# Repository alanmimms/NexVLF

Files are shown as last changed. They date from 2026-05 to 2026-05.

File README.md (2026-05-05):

# NexVLF
This is software defined radio hardware and software for VLF 40kHz to
300kHz range with high noise immunity, dynamic range, sensitivity, and
a built in 1m diameter loop antenna. It could be used to fool around
with VLF, to add a WWVB decoder to your shack (one is planned in
software), or whatever you like.

# Architecture

NexVLF uses an STM32H753 microcontroller to control and shovel bits
from the AK5572 24-bit audio codec into a USB2 (480Mb/s "high speed")
audio interface. A host CPU runs an app built for Linux, MacOS, and
Windows supplying the DSP functions to demodulate and tune the SDR
samples and a flexible and easily extensible receiver GUI mostly
written in Lua.

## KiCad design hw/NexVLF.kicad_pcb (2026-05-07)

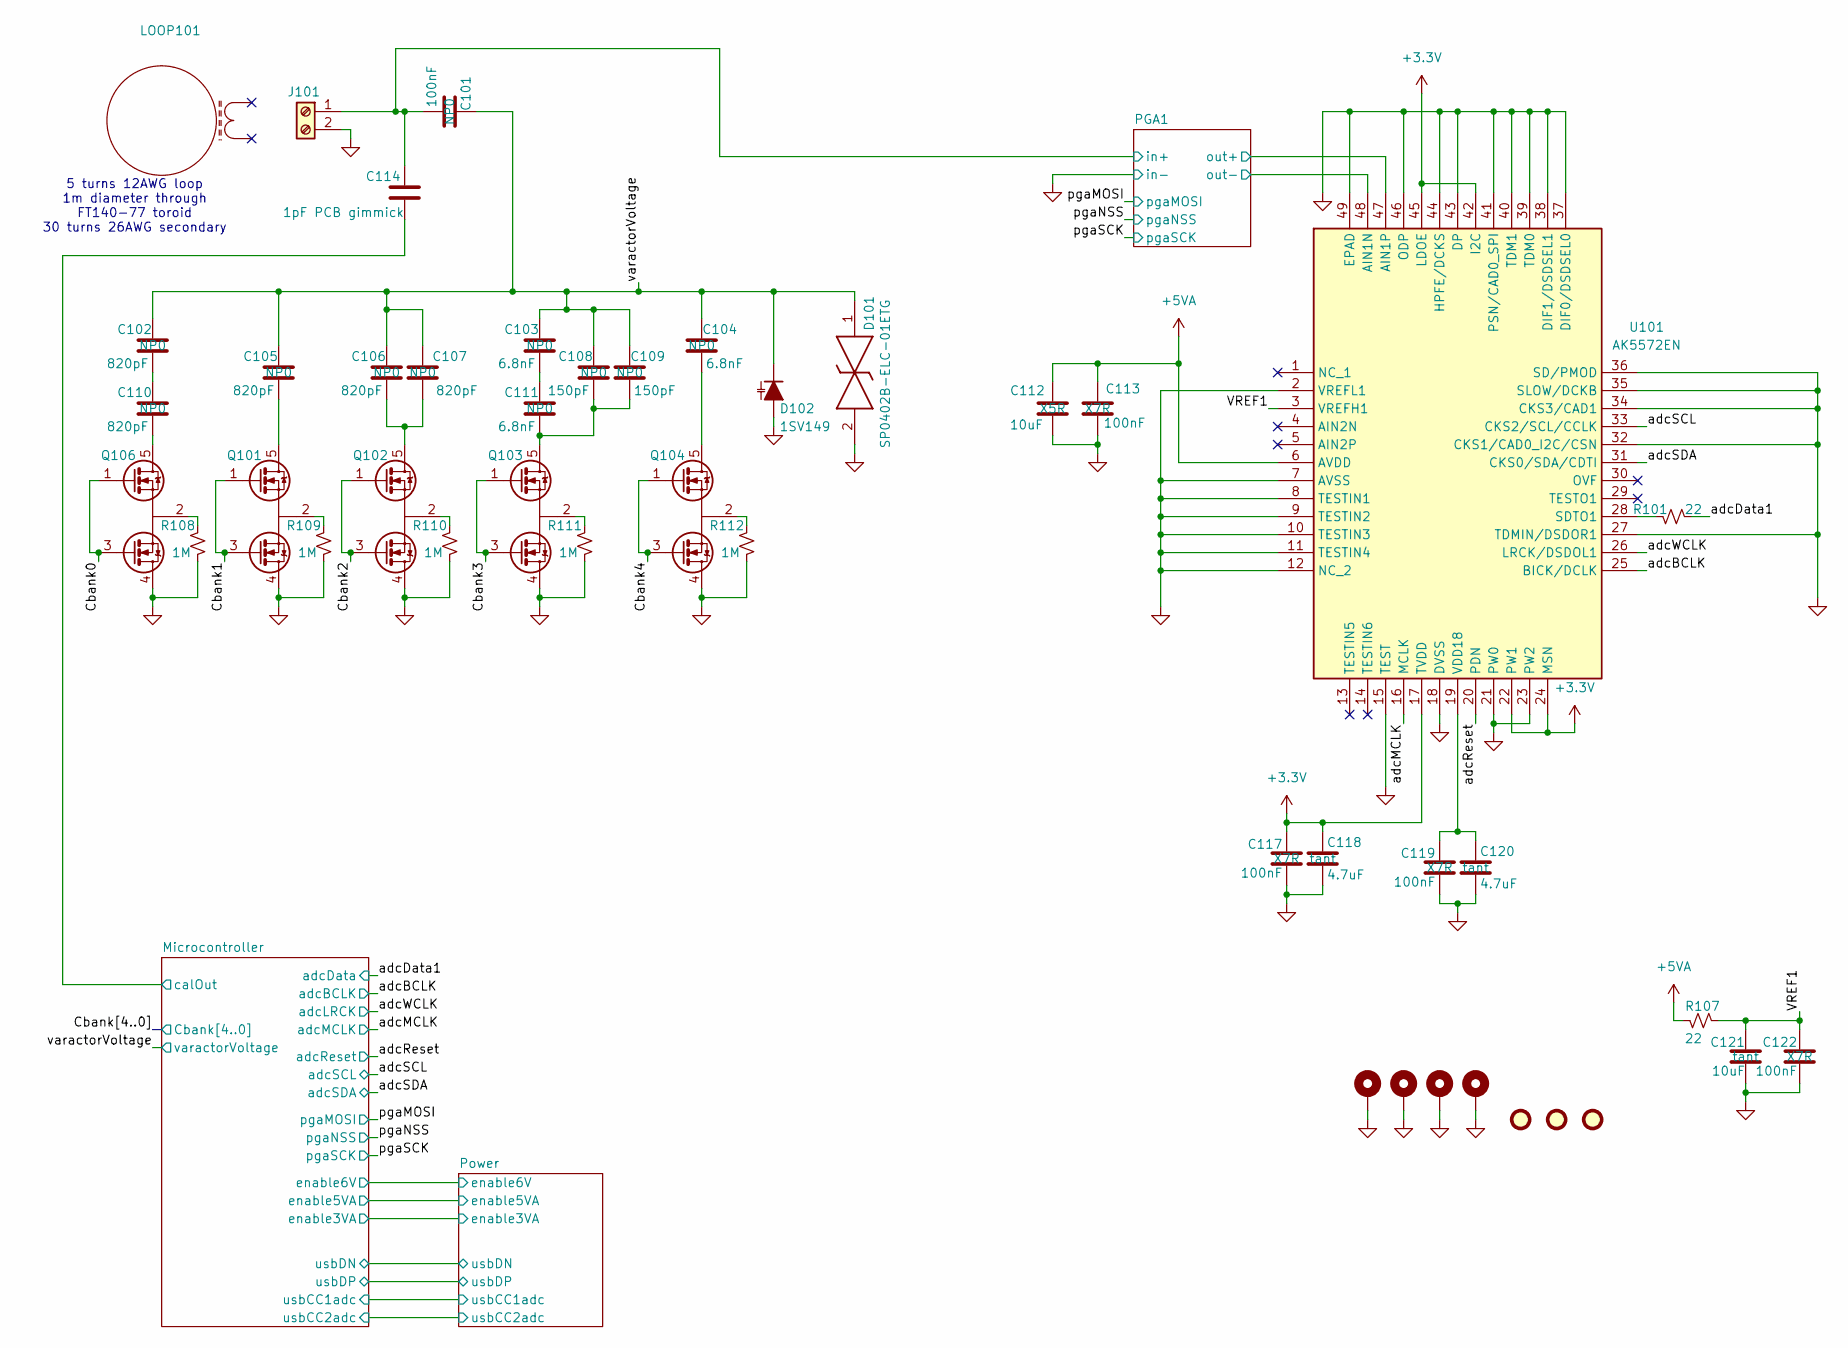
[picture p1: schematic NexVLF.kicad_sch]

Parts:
C101: 100nF; C_1206_3216Metric; MPN GRM3195C2A104JA01D; LCSC_PN C170182
C102, C105, C106, C107, C110: 820pF; C_1206_3216Metric; MPN GRM3195C2A104JA01D; LCSC_PN C170182
C103, C104, C111: 6.8nF; C_1206_3216Metric; MPN GRM3195C2A104JA01D; LCSC_PN C170182
C108, C109: 150pF; C_1206_3216Metric; MPN GRM3195C2A104JA01D; LCSC_PN C170182
C112: 10uF; C_0402_1005Metric; MPN GRM155R61E105KE11D; LCSC_PN C301928
C113, C117, C119, C122: 100nF; C_0402_1005Metric; MPN C0805F104K1RACAUTO; LCSC_PN C24452
C114: 1pF PCB gimmick; PCB-gimmick-1pF
C118, C120: 4.7uF; C_0805_2012Metric; MPN 298D475X9010M2T; LCSC_PN C18535241
C121: 10uF; C_0805_2012Metric; MPN TAJD106K050RNJ; LCSC_PN C4983748
D101: SP0402B-ELC-01ETG; D_0402_1005Metric; MPN SP0402B-ELC-01ETG; LCSC_PN C1974049
D102: 1SV149; TO-92-2
FID101, FID102, FID103: Fiducial; Fiducial_0.5mm_Mask1.5mm
H101, H102, H103, H104: MountingHole_Pad; MountingHole_3.2mm_M3_DIN965_Pad
J101: ANT; Altech_AK300_1x02_P5.00mm_45-Degree
LOOP101: (no value)
Q101, Q102, Q103, Q104, Q106: DMN32D2LDF; SOT-353_SC-70-5
R101, R107: 22; R_0402_1005Metric; JLCPCBpn C4258780
R108, R109, R110, R111, R112: 1M; R_0402_1005Metric; JLCPCBpn C4258780
U101: AK5572EN; QFN50P700X700X100-49N-D; Mouser Part Number 412-AK5572EN

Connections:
+3.3V: C117.2, C118.2, U101.17 (TVDD), U101.22 (PW1), U101.24 (MSN), U101.42 (I2C), U101.45 (LDOE); also elsewhere on the board
+5VA: C112.1, C113.1, R107.2, U101.6 (AVDD); also elsewhere on the board
/Cbank0: Q106.1 (G1), Q106.3 (G2); also elsewhere on the board
/Cbank1: Q101.1 (G1), Q101.3 (G2); also elsewhere on the board
/Cbank2: Q102.1 (G1), Q102.3 (G2); also elsewhere on the board
/Cbank3: Q103.1 (G1), Q103.3 (G2); also elsewhere on the board
/Cbank4: Q104.1 (G1), Q104.3 (G2); also elsewhere on the board
/PGA1/in+: C101.2, C114.1, J101.1; also elsewhere on the board
/PGA1/out+: U101.47 (AIN1P); also elsewhere on the board
/PGA1/out-: U101.48 (AIN1N); also elsewhere on the board
/VREF1: C121.1, C122.1, R107.1, U101.3 (VREFH1)
/adcBCLK: U101.25 (BICK/DCLK); also elsewhere on the board
/adcData1: R101.1; also elsewhere on the board
/adcMCLK: U101.16 (MCLK); also elsewhere on the board
/adcReset: U101.20 (PDN); also elsewhere on the board
/adcSCL: U101.33 (CKS2/SCL/CCLK); also elsewhere on the board
/adcSDA: U101.31 (CKS0/SDA/CDTI); also elsewhere on the board
/adcWCLK: U101.26 (LRCK/DSDOL1); also elsewhere on the board
/varactorVoltage: C101.1, C102.1, C103.1, C104.1, C105.1, C106.1, C107.1, C108.1, C109.1, D101.1, D102.1 (K); also elsewhere on the board
GND: C112.2, C113.2, C117.1, C118.1, C119.1, C120.1, C121.2, C122.2, D101.2, D102.2 (A), H101.1, H102.1, H103.1, H104.1, J101.2, Q101.4 (D2), Q102.4 (D2), Q103.4 (D2), Q104.4 (D2), Q106.4 (D2), R108.2, R109.2, R110.2, R111.2, R112.2, U101.2 (VREFL1), U101.7 (AVSS), U101.8 (TESTIN1), U101.9 (TESTIN2), U101.10 (TESTIN3), U101.11 (TESTIN4), U101.12 (NC_2), U101.15 (TEST), U101.18 (DVSS), U101.21 (PW0), U101.23 (PW2), U101.27 (TDMIN/DSDOR1), U101.32 (CKS1/CAD0_I2C/CSN), U101.34 (CKS3/CAD1), U101.35 (SLOW/DCKB), U101.36 (SD/PMOD), U101.37 (DIF0/DSDSEL0), U101.38 (DIF1/DSDSEL1), U101.39 (TDM0), U101.40 (TDM1), U101.41 (PSN/CAD0_SPI), U101.43 (DP), U101.44 (HPFE/DCKS), U101.46 (ODP), U101.49 (EPAD); also elsewhere on the board
unnamed: C102.2, C110.1
unnamed: C103.2, C111.1
unnamed: C105.2, Q101.5 (D1)
unnamed: Q101.2 (S), R109.1
unnamed: C106.2, C107.2, Q102.5 (D1)
unnamed: Q102.2 (S), R110.1
unnamed: C108.2, C109.2, C111.2, Q103.5 (D1)
unnamed: Q103.2 (S), R111.1
unnamed: C104.2, Q104.5 (D1)
unnamed: Q104.2 (S), R112.1
unnamed: C110.2, Q106.5 (D1)
unnamed: Q106.2 (S), R108.1
unnamed: R101.2, U101.28 (SDTO1)
unnamed: C119.2, C120.2, U101.19 (VDD18)

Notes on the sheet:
5 turns 12AWG loop 1m diameter through FT140-77 toroid 30 turns 26AWG secondary

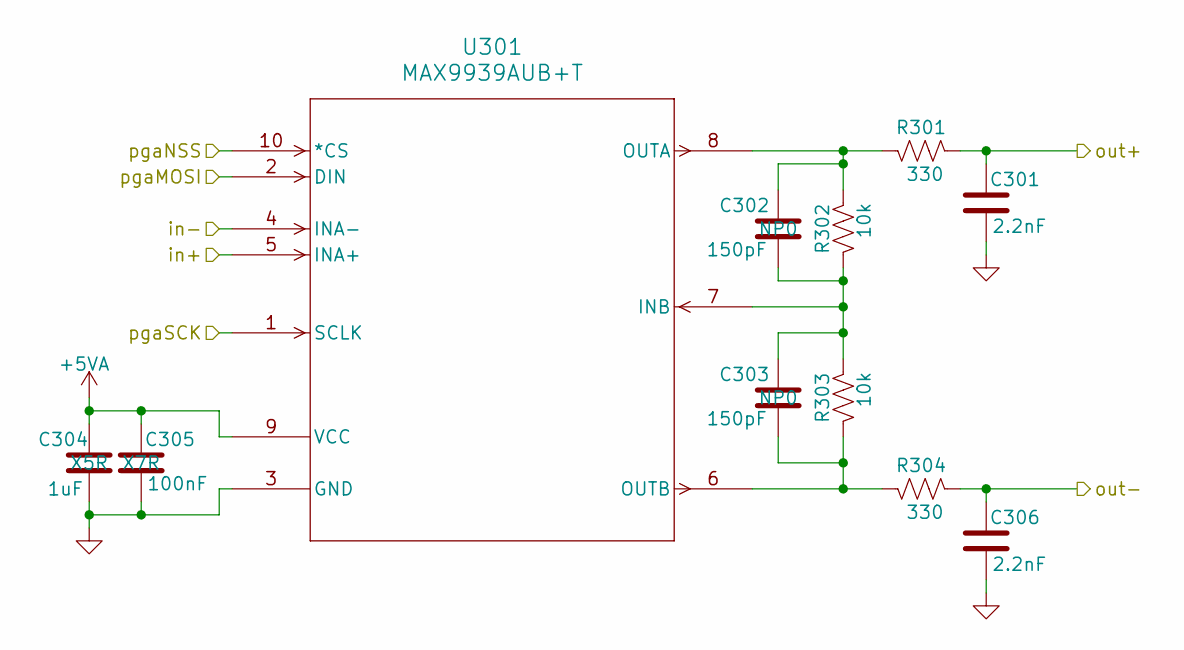
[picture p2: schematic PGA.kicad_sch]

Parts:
C301, C306: 2.2nF; C_0603_1608Metric
C302, C303: 150pF; C_0603_1608Metric; MPN 06033A151FAT2A; LCSC_PN C107038
C304: 1uF; C_0402_1005Metric; MPN GRM155R61E105KE11D; LCSC_PN C301928
C305: 100nF; C_0402_1005Metric; MPN C0805F104K1RACAUTO; LCSC_PN C24452
R301, R304: 330; R_0402_1005Metric; LCSC_PN C854274
R302, R303: 10k; R_0402_1005Metric; JLCPCBpn C723366
U301: MAX9939AUB+T; SOP50P490X110-10N; LCSC_PN C2057611

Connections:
+5VA: C304.1, C305.1, U301.9 (VCC); also elsewhere on the board
/PGA1/in+: U301.5 (INA+); also elsewhere on the board
/PGA1/out+: C301.1, R301.2; also elsewhere on the board
/PGA1/out-: C306.1, R304.2; also elsewhere on the board
/pgaMOSI: U301.2 (DIN); also elsewhere on the board
/pgaNSS: U301.10 (*CS); also elsewhere on the board
/pgaSCK: U301.1 (SCLK); also elsewhere on the board
GND: C301.2, C304.2, C305.2, C306.2, U301.3 (GND), U301.4 (INA-); also elsewhere on the board
unnamed: C302.2, C303.1, R302.2, R303.1, U301.7 (INB)
unnamed: C302.1, R301.1, R302.1, U301.8 (OUTA)
unnamed: C303.2, R303.2, R304.1, U301.6 (OUTB)

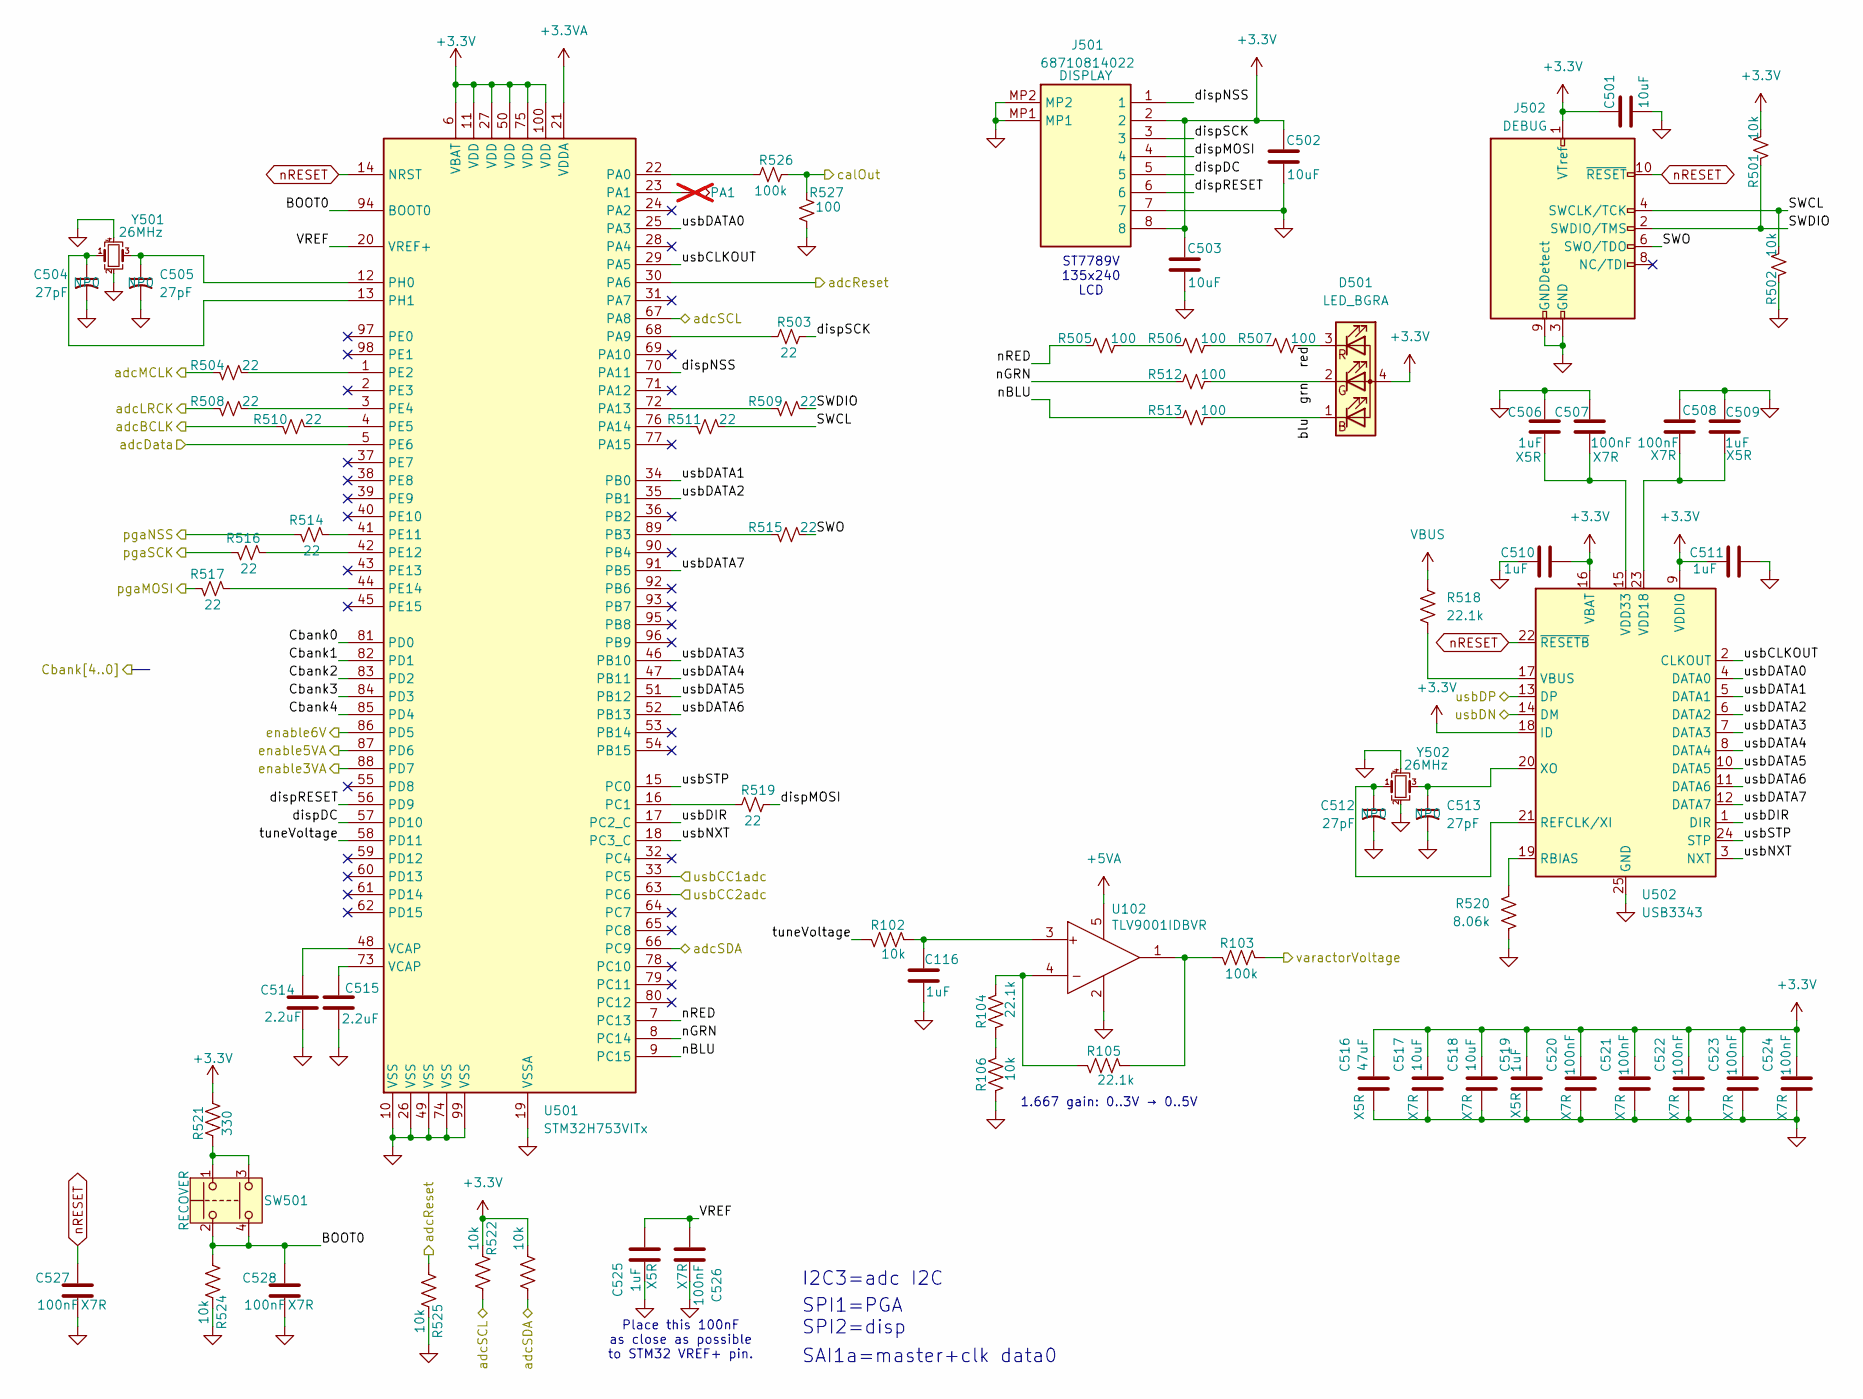
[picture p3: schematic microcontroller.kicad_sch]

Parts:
C116, C506, C509, C510, C511: 1uF; C_0402_1005Metric; Manufacturer_Part_Number GRM155R61E105KE11D; Mouser Part Number 81-GRM155R61E105KE1D
C501, C503: 10uF; C_0603_1608Metric; MPN 81-GXT155R71E223KE1D; LCSC_PN C327087
C502, C517, C518: 10uF; C_0603_1608Metric; Manufacturer_Part_Number 81-GXT155R71E223KE1D; Mouser Part Number 963-MLAST168BB5106MT
C504: 27pF; C_0402_1005Metric; LCSC_PN C107045
C505, C512, C513: 27pF; C_0402_1005Metric; JLCPCBpn C107045
C507, C508, C524: 100nF; C_0402_1005Metric; MPN C0805F104K1RACAUTO; LCSC_PN C24452
C514, C515: 2.2uF; C_0603_1608Metric; LCSC_PN C100082
C516: 47uF; C_1206_3216Metric; MPN TCTAL1A107M8R-V1; LCSC_PN C403725
C519, C525: 1uF; C_0402_1005Metric; MPN GRM155R61E105KE11D; LCSC_PN C301928
C520, C521, C522, C523, C526, C527, C528: 100nF; C_0402_1005Metric
D501: LED_BGRA; UHD111AFKAC3K23E1L3VG5ZB3Z3; MPN UHD111A-FKA-C3K23E1L3VG5ZB3Z3; Mouser_PN 941-UHD1AA3K3E3V53Z3
J501: 68710814022; MPN 5034800800; LCSC_PN C293338
J502: FTSH-105-01-L-DV-K; FTSH10501LDVK; LCSC_PN C5155080
PG501: PA1; TestPoint_Pad_1.0x1.0mm; not fitted
R102, R106: 10k; R_0402_1005Metric; JLCPCBpn C723366
R103: 100k; R_0402_1005Metric; LCSC_PN C728576
R104, R105: 22.1k; R_0402_1005Metric; JLCPCBpn C723366
R501, R502, R522, R523, R524, R525: 10k; R_0402_1005Metric; LCSC_PN C723366
R503, R504, R508, R509, R511, R514, R515, R516, R517, R519: 22; R_0402_1005Metric; JLCPCBpn C4258780
R505, R506, R507, R512, R513: 100; R_0402_1005Metric
R510: 22; R_0402_1005Metric; LCSC_PN C4258780
R518: 22.1k; R_0402_1005Metric; LCSC_PN C284424
R520: 8.06k; R_0402_1005Metric; LCSC_PN C863964
R521: 330; R_0402_1005Metric; LCSC_PN C723366
R526: 100k; R_0402_1005Metric; JLCPCBpn C4258780
R527: 100; R_0402_1005Metric; JLCPCBpn C4258780
SW501: Push button switch; EVQPUC02K
U102: TLV9001IDBVR; SOT95P280X145-5N; Mouser Part Number 595-TLV9001IDBVR
U501: STM32H753VITx; LQFP-100_14x14mm_P0.5mm; LCSC_PN C730206
U502: USB3343; QFN-24-1EP_4x4mm_P0.5mm_EP2.6x2.6mm; MPN USB3343-CP-TR; LCSC_PN C633347
Y501, Y502: 26MHz; Crystal_SMD_2520-4Pin_2.5x2.0mm; MPN E2X260181G01; LCSC_PN C712894

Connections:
+3.3V: C501.2, C502.2, C503.2, C510.2, C511.1, C516.1, C517.1, C518.1, C519.1, C520.1, C521.1, C522.1, C523.1, C524.1, D501.4 (A), J501.2, J501.8, J502.1 (VTref), R501.1, R521.1, R522.1, R523.1, U501.6 (VBAT), U501.11 (VDD), U501.27 (VDD), U501.50 (VDD), U501.75 (VDD), U501.100 (VDD), U502.9 (VDDIO), U502.16 (VBAT), U502.18 (ID); also elsewhere on the board
+3.3VA: U501.21 (VDDA); also elsewhere on the board
+5VA: U102.5 (V+); also elsewhere on the board
/Cbank0: U501.81 (PD0); also elsewhere on the board
/Cbank1: U501.82 (PD1); also elsewhere on the board
/Cbank2: U501.83 (PD2); also elsewhere on the board
/Cbank3: U501.84 (PD3); also elsewhere on the board
/Cbank4: U501.85 (PD4); also elsewhere on the board
/Microcontroller/BOOT0: C528.1, R524.1, SW501.2, SW501.4, U501.94 (BOOT0)
/Microcontroller/SWCL: J502.4 (SWCLK/TCK), R502.1, R511.1
/Microcontroller/SWDIO: J502.2 (SWDIO/TMS), R501.2, R509.1
/Microcontroller/SWO: J502.6 (SWO/TDO), R515.1
/Microcontroller/VREF: C525.1, C526.1, U501.20 (VREF+)
/Microcontroller/blu: D501.1 (BK), R513.2
/Microcontroller/calOut: R526.2, R527.2
/Microcontroller/dispDC: J501.5, U501.57 (PD10)
/Microcontroller/dispMOSI: J501.4, R519.2
/Microcontroller/dispNSS: J501.1, U501.70 (PA11)
/Microcontroller/dispRESET: J501.6, U501.56 (PD9)
/Microcontroller/dispSCK: J501.3, R503.2
/Microcontroller/enable3VA: U501.88 (PD7); also elsewhere on the board
/Microcontroller/enable5VA: U501.87 (PD6); also elsewhere on the board
/Microcontroller/enable6V: U501.86 (PD5); also elsewhere on the board
/Microcontroller/grn: D501.2 (GK), R512.2
/Microcontroller/nBLU: R513.1, U501.9 (PC15)
/Microcontroller/nGRN: R512.1, U501.8 (PC14)
/Microcontroller/nRED: R505.1, U501.7 (PC13)
/Microcontroller/red: D501.3 (RK), R507.2
/Microcontroller/tuneVoltage: R102.2, U501.58 (PD11)
/Microcontroller/usbCC1adc: U501.33 (PC5); also elsewhere on the board
/Microcontroller/usbCC2adc: U501.63 (PC6); also elsewhere on the board
/Microcontroller/usbCLKOUT: U501.29 (PA5), U502.2 (CLKOUT)
/Microcontroller/usbDATA0: U501.25 (PA3), U502.4 (DATA0)
/Microcontroller/usbDATA1: U501.34 (PB0), U502.5 (DATA1)
/Microcontroller/usbDATA2: U501.35 (PB1), U502.6 (DATA2)
/Microcontroller/usbDATA3: U501.46 (PB10), U502.7 (DATA3)
/Microcontroller/usbDATA4: U501.47 (PB11), U502.8 (DATA4)
/Microcontroller/usbDATA5: U501.51 (PB12), U502.10 (DATA5)
/Microcontroller/usbDATA6: U501.52 (PB13), U502.11 (DATA6)
/Microcontroller/usbDATA7: U501.91 (PB5), U502.12 (DATA7)
/Microcontroller/usbDIR: U501.17 (PC2_C), U502.1 (DIR)
/Microcontroller/usbDN: U502.14 (DM); also elsewhere on the board
/Microcontroller/usbDP: U502.13 (DP); also elsewhere on the board
/Microcontroller/usbNXT: U501.18 (PC3_C), U502.3 (NXT)
/Microcontroller/usbSTP: U501.15 (PC0), U502.24 (STP)
/adcBCLK: R510.2; also elsewhere on the board
/adcData1: U501.5 (PE6); also elsewhere on the board
/adcMCLK: R504.2; also elsewhere on the board
/adcReset: R525.1, U501.30 (PA6); also elsewhere on the board
/adcSCL: R522.2, U501.67 (PA8); also elsewhere on the board
/adcSDA: R523.2, U501.66 (PC9); also elsewhere on the board
/adcWCLK: R508.2; also elsewhere on the board
/pgaMOSI: R517.2; also elsewhere on the board
/pgaNSS: R514.2; also elsewhere on the board
/pgaSCK: R516.2; also elsewhere on the board
/varactorVoltage: R103.1; also elsewhere on the board
GND: C116.1, C501.1, C502.1, C503.1, C504.2, C505.2, C506.2, C507.1, C508.1, C509.2, C510.1, C511.2, C512.2, C513.2, C514.2, C515.2, C516.2, C517.2, C518.2, C519.2, C520.2, C521.2, C522.2, C523.2, C524.2, C525.2, C526.2, C527.2, C528.2, J501.7, J501.MP1, J501.MP2, J502.3 (GND), J502.5 (GND), J502.9 (GNDDetect), R106.2, R502.2, R520.2, R524.2, R525.2, R527.1, U102.2 (V-), U501.10 (VSS), U501.19 (VSSA), U501.26 (VSS), U501.49 (VSS), U501.74 (VSS), U501.99 (VSS), U502.25 (GND), Y501.2, Y501.4, Y502.2, Y502.4; also elsewhere on the board
unnamed: C514.1, U501.48 (VCAP)
unnamed: C515.1, U501.73 (VCAP)
unnamed: R104.2, R106.1
unnamed: R505.2, R506.1
unnamed: R506.2, R507.1
unnamed: R521.2, SW501.1, SW501.3
unnamed: C116.2, R102.1, U102.3 (IN+)
unnamed: R104.1, R105.2, U102.4 (IN-)
unnamed: R103.2, R105.1, U102.1 (OUT)
unnamed: R526.1, U501.22 (PA0)
unnamed: PG501.1, U501.23 (PA1)
unnamed: R503.1, U501.68 (PA9)
unnamed: R509.2, U501.72 (PA13)
unnamed: R511.2, U501.76 (PA14)
unnamed: R515.2, U501.89 (PB3)
unnamed: R519.1, U501.16 (PC1)
unnamed: R504.1, U501.1 (PE2)
unnamed: R508.1, U501.3 (PE4)
unnamed: R510.1, U501.4 (PE5)
unnamed: R514.1, U501.41 (PE11)
unnamed: R516.1, U501.42 (PE12)
unnamed: R517.1, U501.44 (PE14)
unnamed: C505.1, U501.12 (PH0), Y501.3
unnamed: C504.1, U501.13 (PH1), Y501.1
unnamed: R520.1, U502.19 (RBIAS)
unnamed: C512.1, U502.21 (REFCLK/XI), Y502.1
unnamed: R518.2, U502.17 (VBUS)
unnamed: C508.2, C509.1, U502.23 (VDD18)
unnamed: C506.1, C507.2, U502.15 (VDD33)
unnamed: C513.1, U502.20 (XO), Y502.3
VBUS: R518.1; also elsewhere on the board
nRESET: C527.1, J502.10 (~RESET), U501.14 (NRST), U502.22 (~RESETB)

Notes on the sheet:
SPI1=PGA SPI2=disp
SAI1a=master+clk data0
1.667 gain: 0..3V → 0..5V
Place this 100nF as close as possible to STM32 VREF+ pin.
I2C3=adc I2C
ST7789V 135x240 LCD

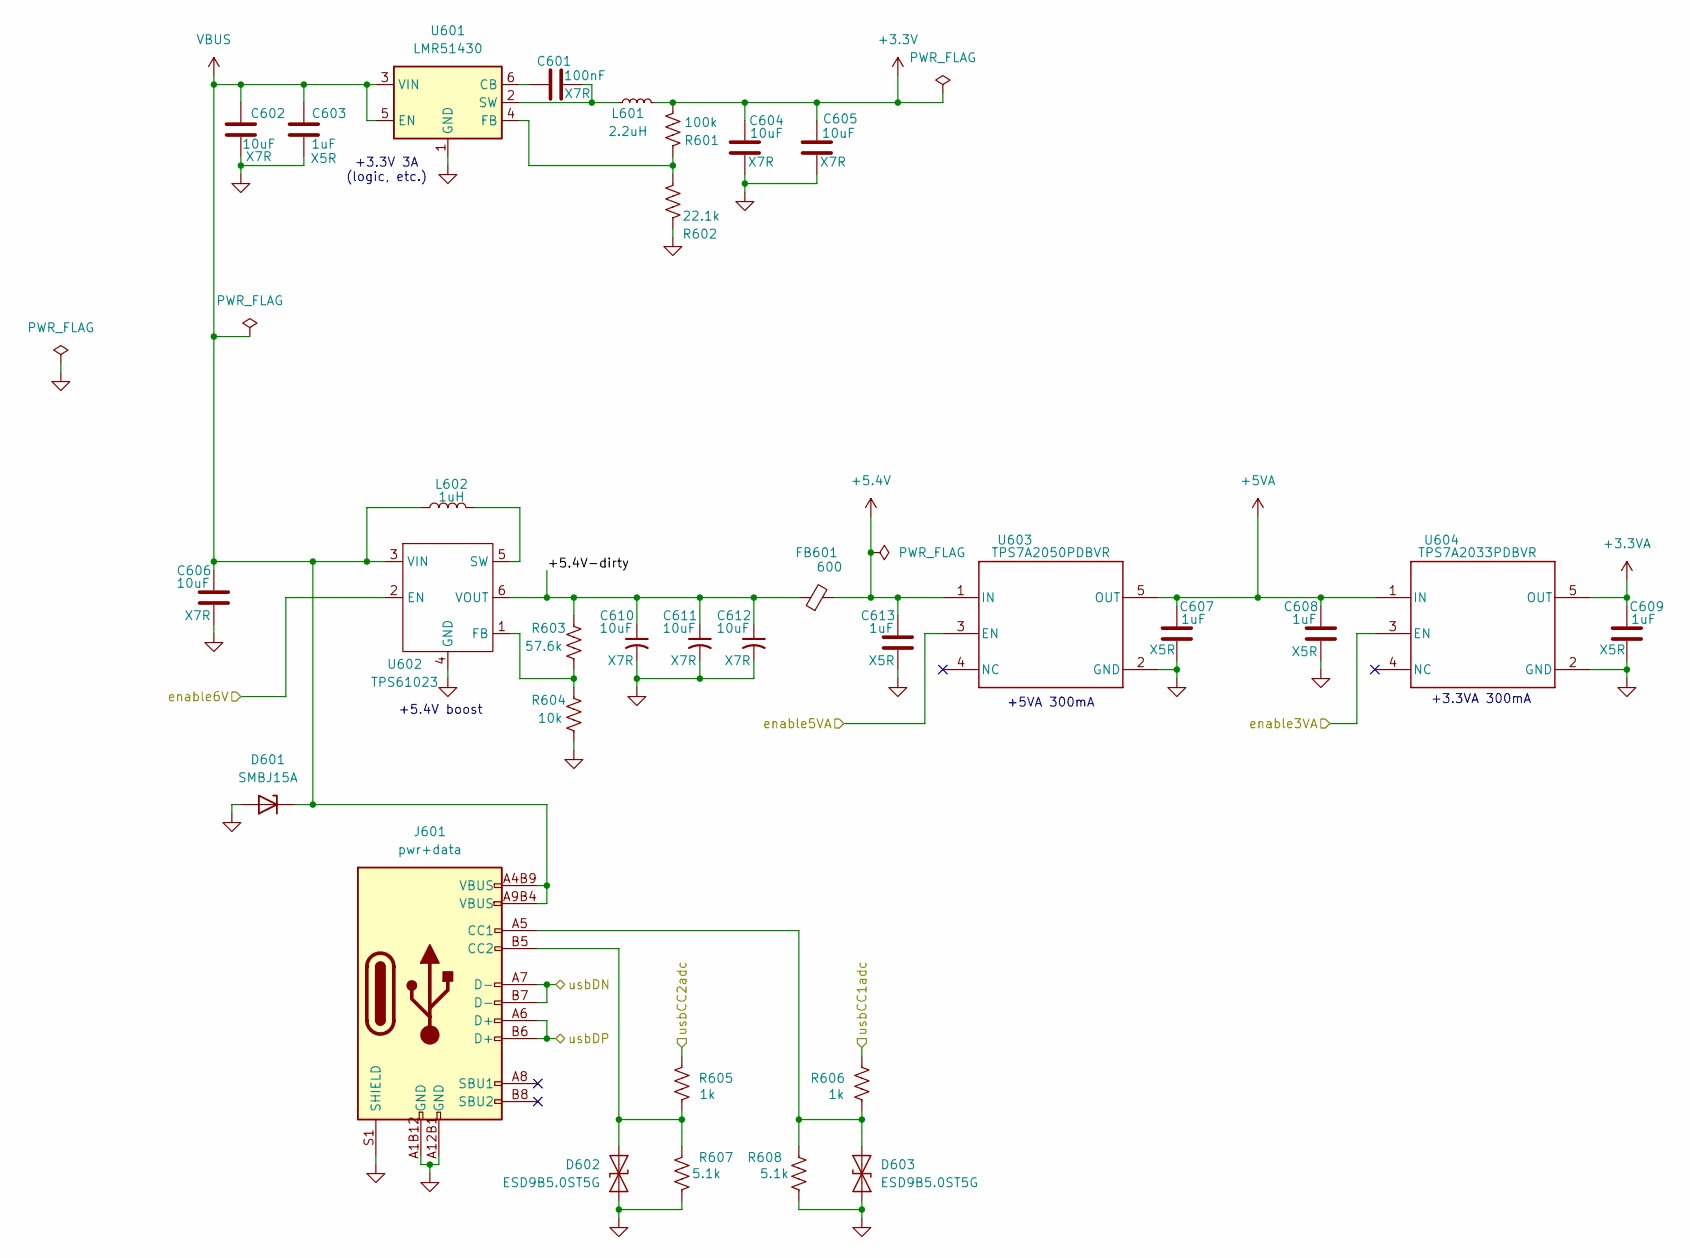
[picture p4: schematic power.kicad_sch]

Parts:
C601: 100nF; C_0402_1005Metric; MPN C0805F104K1RACAUTO; LCSC_PN C24452
C602, C606, C612: 10uF; C_0603_1608Metric; MPN 81-GXT155R71E223KE1D; LCSC_PN C327087
C603, C607, C613: 1uF; C_0402_1005Metric; MPN GRM155R61E105KE11D; LCSC_PN C301928
C604, C605, C610, C611: 10uF; C_0603_1608Metric; Manufacturer_Part_Number 81-GXT155R71E223KE1D; Mouser Part Number 963-MLAST168BB5106MT
C608, C609: 1uF; C_0402_1005Metric; Manufacturer_Part_Number GRM155R61E105KE11D; Mouser Part Number 81-GRM155R61E105KE1D
D601: SMBJ15A; D_SMB; MPN SMBJ15A; LCSC_PN C83846
D602, D603: ESD9B5.0ST5G; D_SOD-923; LCSC_PN C111566
FB601: 600; L_0603_1608Metric; MPN MI0603J601R-10; LCSC_PN C2441365
J601: pwr+data; USB_C_Receptacle_HRO_TYPE-C-31-M-12-bursted; MPN TYPE-C-31-M-12; LCSC_PN C165948
L601: 2.2uH; L_0805_2012Metric; Part Number LQM21PN2R2NGCD; LCSC_PN C86089
L602: 1uH; IND_XGL4030_COC; MPN XGL4030-102MEC; LCSC_PN C6336766
R601: 100k; R_0402_1005Metric; LCSC_PN C728576
R602: 22.1k; R_0402_1005Metric; LCSC_PN C284424
R603: 57.6k; R_0402_1005Metric; LCSC_PN C517765
R604: 10k; R_0402_1005Metric; LCSC_PN C723366
R605, R606: 1k; R_0402_1005Metric; LCSC_PN C136974
R607, R608: 5.1k; R_0402_1005Metric; LCSC_PN C854378
U601: LMR51430; SOT-23-6; LCSC_PN C5185863
U602: TPS61023; SOT-563; LCSC_PN C919459
U603: TPS7A2050PDBVR; DBV0005A-MFG; LCSC_PN C36907702
U604: TPS7A2033PDBVR; DBV0005A-MFG; LCSC_PN C36907702

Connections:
+3.3V: C604.1, C605.1, L601.2, R601.2; also elsewhere on the board
+3.3VA: C609.1, U604.5 (OUT); also elsewhere on the board
+5.4V: C613.1, FB601.2, U603.1 (IN)
+5VA: C607.1, C608.1, U603.5 (OUT), U604.1 (IN); also elsewhere on the board
/Microcontroller/enable3VA: U604.3 (EN); also elsewhere on the board
/Microcontroller/enable5VA: U603.3 (EN); also elsewhere on the board
/Microcontroller/enable6V: U602.2 (EN); also elsewhere on the board
/Microcontroller/usbCC1adc: R606.1; also elsewhere on the board
/Microcontroller/usbCC2adc: R605.1; also elsewhere on the board
/Microcontroller/usbDN: J601.A7 (D-), J601.B7 (D-); also elsewhere on the board
/Microcontroller/usbDP: J601.A6 (D+), J601.B6 (D+); also elsewhere on the board
/Power/+5.4V-dirty: C610.1, C611.1, C612.1, FB601.1, R603.2, U602.6 (VOUT)
GND: C602.2, C603.2, C604.2, C605.2, C606.2, C607.2, C608.2, C609.2, C610.2, C611.2, C612.2, C613.2, D601.2 (A), D602.1 (A1), D603.1 (A1), J601.A1B12 (GND), J601.A12B1 (GND), J601.S1 (SHIELD), R602.1, R604.1, R607.2, R608.2, U601.1 (GND), U602.4 (GND), U603.2 (GND), U604.2 (GND); also elsewhere on the board
unnamed: D602.2 (A2), J601.B5 (CC2), R605.2, R607.1
unnamed: D603.2 (A2), J601.A5 (CC1), R606.2, R608.1
unnamed: C601.1, U601.6 (CB)
unnamed: R601.1, R602.2, U601.4 (FB)
unnamed: C601.2, L601.1, U601.2 (SW)
unnamed: R603.1, R604.2, U602.1 (FB)
unnamed: L602.2, U602.5 (SW)
VBUS: C602.1, C603.1, C606.1, D601.1 (K), J601.A4B9 (VBUS), J601.A9B4 (VBUS), L602.1, U601.3 (VIN), U601.5 (EN), U602.3 (VIN); also elsewhere on the board

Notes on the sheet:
+3.3V 3A (logic, etc.)
+5.4V boost
+3.3VA 300mA
+5VA 300mA

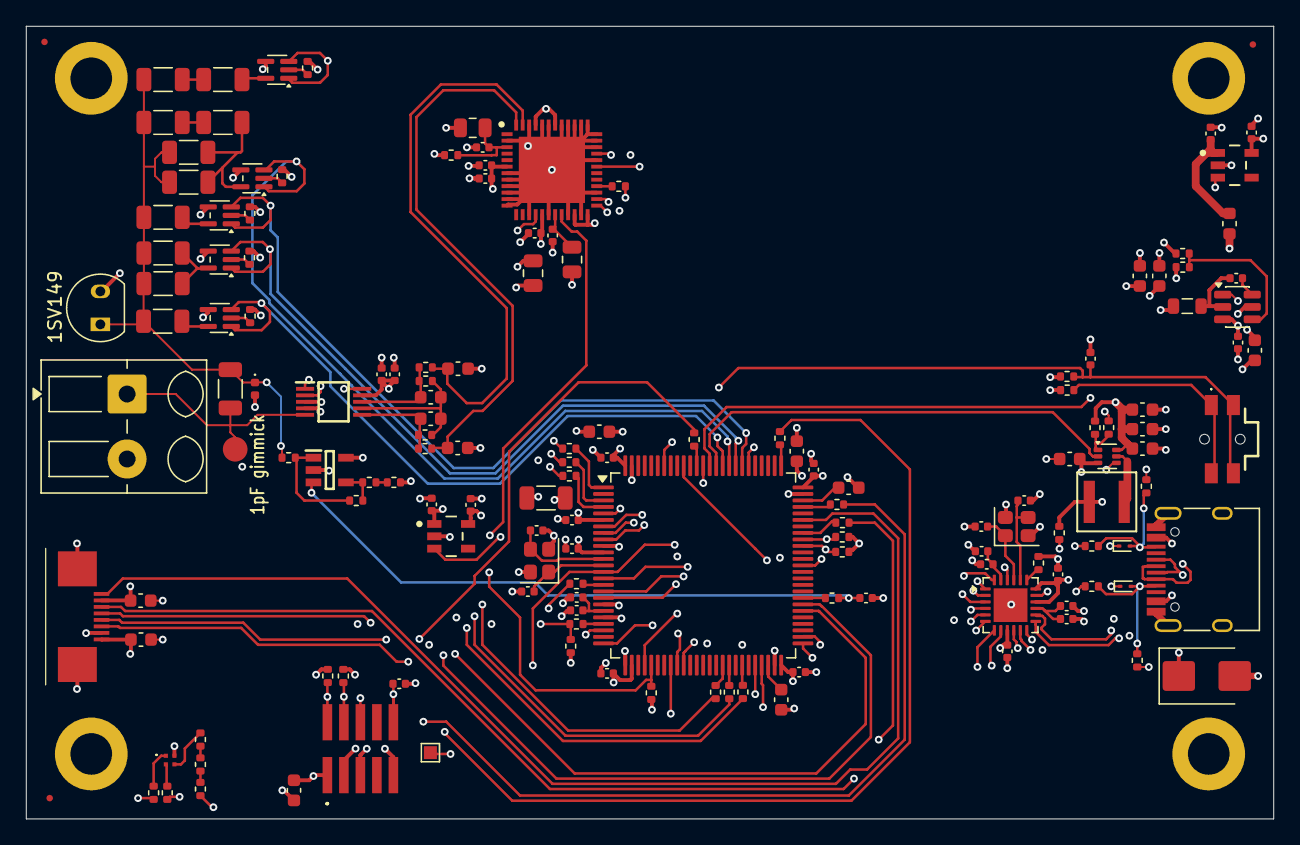
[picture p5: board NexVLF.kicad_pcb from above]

Board: 6 copper layers, 96.0 x 61.0 mm, 156 parts (0 on the bottom side), 119 nets.

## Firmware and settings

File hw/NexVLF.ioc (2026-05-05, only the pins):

Mcu.UserName=STM32H753VITx
PA11.GPIO_Label=dispNSS
PA11.Signal=SPI2_NSS
PA3.GPIO_Label=usbDATA0
PA3.Signal=USB_OTG_HS_ULPI_D0
PA4.Signal=COMP_DAC11_group
PA5.GPIO_Label=usbCLKOUT
PA5.Signal=USB_OTG_HS_ULPI_CK
PA8.GPIO_Label=audioSCL
PA8.Signal=I2C3_SCL
PA9.GPIO_Label=dispSCK
PA9.Signal=SPI2_SCK
PB0.GPIO_Label=usbDATA1
PB0.Signal=USB_OTG_HS_ULPI_D1
PB1.GPIO_Label=usbDATA2
PB1.Signal=USB_OTG_HS_ULPI_D2
PB10.GPIO_Label=usbDATA3
PB10.Signal=USB_OTG_HS_ULPI_D3
PB11.GPIO_Label=usbDATA4
PB11.Signal=USB_OTG_HS_ULPI_D4
PB12.GPIO_Label=usbDATA5
PB12.Signal=USB_OTG_HS_ULPI_D5
PB13.GPIO_Label=usbDATA6
PB13.Signal=USB_OTG_HS_ULPI_D6
PB5.GPIO_Label=usbDATA7
PB5.Signal=USB_OTG_HS_ULPI_D7
PC0.GPIO_Label=usbSTP
PC0.Signal=USB_OTG_HS_ULPI_STP
PC1.GPIO_Label=dispMOSI
PC1.Signal=SPI2_MOSI
PC2_C.GPIO_Label=usbDIR
PC2_C.Signal=USB_OTG_HS_ULPI_DIR
PC3_C.GPIO_Label=usbNXT
PC3_C.Signal=USB_OTG_HS_ULPI_NXT
PC5.GPIO_Label=usbCC1adc
PC5.Signal=GPIO_Analog
PC6.GPIO_Label=usbCC2adc
PC6.Signal=GPIO_Analog
PC9.GPIO_Label=audioSDA
PC9.Signal=I2C3_SDA
PD10.GPIO_Label=dispDC
PD10.Signal=GPIO_Output
PD5.GPIO_Label=enable6V
PD5.Signal=GPIO_Output
PD6.GPIO_Label=enable3V3
PD6.Signal=GPIO_Output
PD7.GPIO_Label=enable3VA
PD7.Signal=GPIO_Output
PD8.GPIO_Label=enable5VA
PD8.Signal=GPIO_Output
PD9.GPIO_Label=dispRESET
PD9.Signal=GPIO_Output
PE11.GPIO_Label=pgaNSS
PE11.Signal=SPI4_NSS
PE12.GPIO_Label=pgaSCK
PE12.Signal=SPI4_SCK
PE14.GPIO_Label=pgaMOSI
PE14.Signal=SPI4_MOSI
PE2.GPIO_Label=audioMCLK
PE2.Signal=SAI1_MCLK_A
PE4.GPIO_Label=audioWCLK
PE4.Signal=SAI1_FS_A
PE5.GPIO_Label=audioBCLK
PE5.Signal=SAI1_SCK_A
PE6.GPIO_Label=audioData
PE6.Signal=SAI1_SD_A

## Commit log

2026-05-05 Starting some layout
    [NexVLF.kicad_pcb, NexVLF.kicad_sch, PGA.kicad_sch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]
2026-05-07 Routing complete for DVT1 all ERC and DRC pass, 3D view is full
    [NexVLF.kicad_pcb, NexVLF.kicad_sch, microcontroller.kicad_sch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]
